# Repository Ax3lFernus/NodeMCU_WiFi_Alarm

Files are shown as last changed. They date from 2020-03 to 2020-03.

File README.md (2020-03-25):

# NodeMCU WiFi Alarm Logo NodeMCU WiFi Alarm
A simple firmware that makes NodeMCU a Wireless alarm center.

  

## Table of Contents
- [Features](#features)
  - [RC522 Support](#rc522-support)
  - [Wireless Connectivity](#wireless-connectivity)
  - [APIs](#apis)
  - [Web Panel](#web-panel)
- [Installation](#installation)
  - [Wiring Diagram](#wiring-diagram)
  - [Flash firmware](#flash-firmware)
  - [Change the timers](#change-the-timers)
  - [Install Web Panel](#install-web-panel)
- [The Author](#the-author)
- [License](#license)

## Features
### RC522 Support
With the RFID-RC522 card it is possible to activate and deactivate the alarm via an RFID tag or card.
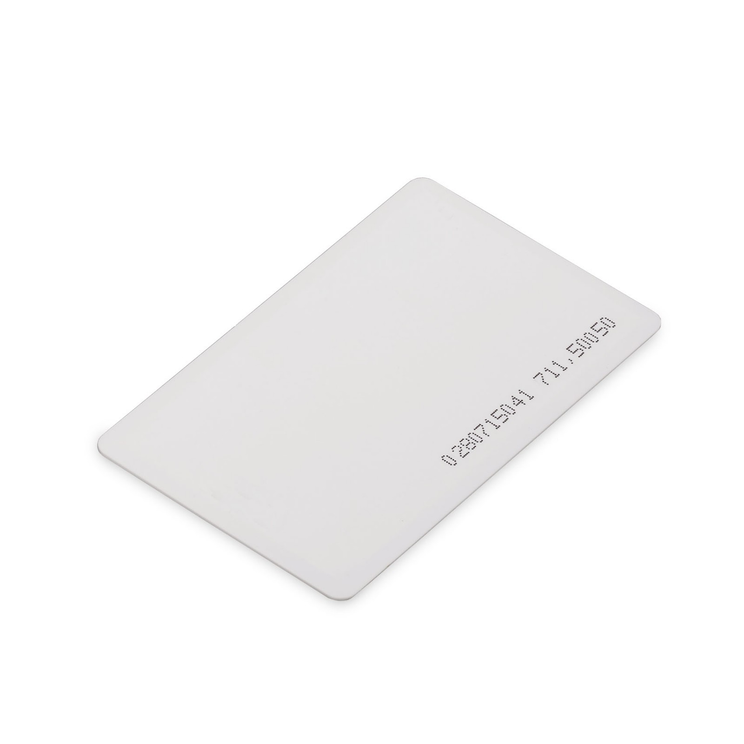
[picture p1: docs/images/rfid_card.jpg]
RFID Card
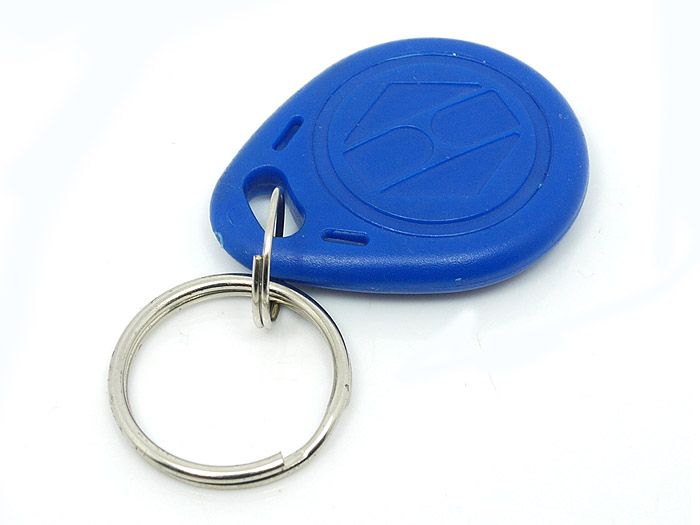
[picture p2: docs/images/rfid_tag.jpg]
RFID Tag
&nbsp;
### Wireless Connectivity
The NodeMCU card was born to have an integrated WiFi NIC. This functionality is used to check the card to read its status through the [APIs](#apis).
### APIs
The APIs provide commands to check and modify the alarm status. 
It is necessary to know the local IP of the card in order to interact with it through HTTP GET requests, the answers are in json format.
Here is the list of possible requests:
<ol>
<li>
To know the status of the card just send the request to http://CARD_IP/status. The answer is formatted as 

| Key | Type | Values | Description |
|---|---|---|---|
|door| String | `open` or `closed` | The value indicates whether the line of pin `D1` is open or closed. |
|h24 | String | `open` or `closed` | The value indicates whether the line of pin `D2` (tamper) is open or closed. |
|active| Bool| `true` or `false` | Indicates the alarm status: active (`true`) or inactive (`false`) |
|alarm | Bool| `true` or `false` | Indicates whether there is an alarm state. If `true`, the siren is in alarm. `false` otherwise. |
</li>
<li>
To activate the alarm just send the request to http://CARD_IP/1/on

| Key | Type | Values | Description |
|---|---|---|---|
|result| Bool | `true` or `false` | If `true`, the alarm is active. If `false`, the alarm is not active. |
|msg | String | - | A message written in natural language useful to describe the `result` key.  |
</li>
<li>
To deactivate the alarm just send the request to http://CARD_IP/1/off

| Key | Type | Values | Description |
|---|---|---|---|
|result| Bool | `true` or `false` | If `true`, the alarm is active. If `false`, the alarm is not active. |
|msg | String | - | A message written in natural language useful to describe the `result` key.  |
</li>
</ol>

### Web Panel

## Installation
### Wiring Diagram
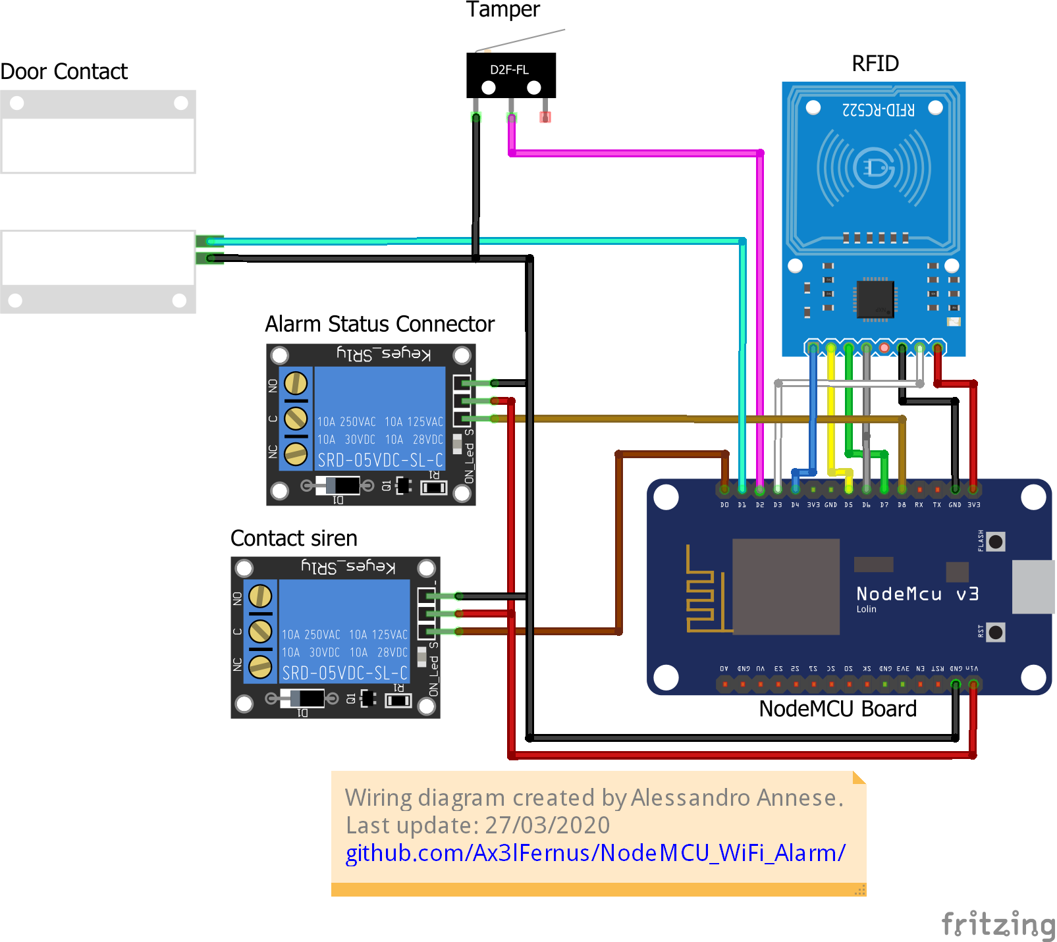
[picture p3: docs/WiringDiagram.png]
Wiring Diagram


The role of each pin used in the board is described below:
|Pin|Description|
| --- | --- |
|D0|It gives the signal to the siren to make it sound|
|D1|Detects the status of the door contact|
|D2|Detects the status of the tamper contact|
|D3|Reserved for the RST pin of the RFID board|
|D4|Reserved for the SDA pin of the RFID board|
|D5|Reserved for the SCK pin of the RFID board|
|D6|Reserved for the MISO pin of the RFID board|
|D7|Reserved for the MOSI pin of the RFID board|
|D8|Indicates the alarm status (enabled/disabled)|

### Flash firmware
You can flash the firmware on the NodeMCU via the [Arduino IDE](https://www.arduino.cc/en/Main/Software).
If you install the id for the first time you will need:
<ol>
<li>
Go to File -> Preferences -> add the link http://arduino.esp8266.com/stable/package_esp8266com_index.json in "Additional Boards Manager URLs" -> Click "OK"
</li>
<li>
Go to Tools -> Board -> click on "Boards Manager" -> search "esp8266" -> select leatest version -> click "Install" -> when finished click "Close"
</li>
<li>
Go to Tools and check this configurations:

| Name | Value |
|---|---|
| Board| NodeMCU 1.0 (ESP-12E Module)|
|Upload Speed| 115200|
|Port|Select the COM port where the board is connected| 
</li> 
<li>
Download the <a href="https://github.com/miguelbalboa/rfid/releases/latest/">source code</a> of the RFID library -> open Arduino IDE and go to Sketch -> Include Library -> Add .ZIP Library... -> select the previously downloaded .zip file -> click Open.
</li>
<li>
Go to File -> Open -> select 'firmware.ino' file from the repository directory on your pc -> when the code opens go to "Network SSID" and "Network PASSWORD" in the code and insert your network credentials between the quotes

`// Network and UID Credentials`<br>
`const char *ssid = "<YOUR WIFI NAME HERE>";          //Network SSID`<br>

`const char *password = "<YOUR WIFI PASSWORD HERE>"; //Network PASSWORD`<br>

`const char *UID = "<UID CARD HERE>";                //UID Card Code`<br>
</li>
<li>
In "UID Card Code" enter the code of your card for enable/disable the alarm.
</li>
<li>
Click on the arrow pointing to the right to flash the card.
</li>
<li>
That's all!
</li>
</ol>

**:information_source: Note:** if you don't know the uid of your card you will need to: flash the card -> open the serial monitor (select the value 115200 as baud rate) -> scan the RFID card -> copy the UID that comes out in the monitor -> go to step 5.

### Change the timers
The alarm has times that can be changed at will:
- Exit time (from when the alarm is activated until the door is detected open)
- Entry time (from when the door is opened to the sound of the siren)
- Alarm time
- Tamper detection time (from when the alarm is deactivated until the open tamper is detected)

Times are expressed in milliseconds. Ex: for 10 seconds we will have to enter the value 10000. 

So `milliseconds = seconds * 1000`.

You can change the value of timers by finding the respective variables in the code:

`// Define siren sound time in case of alarm (in milliseconds, example: 10000ms = 10s)`<br>
`const long alarmTimeout = 180000;`

This line expresses the alarm time. To change it to 10 seconds just change the variable:

`const long alarmTimeout = 10000;`

This applies to all timers.

**:warning: Danger zone:** It isn't recommended to change the `timeoutTime` variable as it is reserved for the Web server.

### Install Web Panel
The web panel doesn't require installation so you can open `./webServer/index.html` with a browser without using additional programs. The only step is to open the `index.html` with a text editor (es. Notepad++) and insert the ip of the card in the local network in the field `nodemcu_ip`:<br>
`let nodemcu_ip = "<NODEMCU IP HERE>" //Set your NodeMCU IP ex: 192.168.1.1`<br>
However, you can upload the `index.html` to a web server to be able to visit it from other devices on the same local network.

**:warning: Warning:** the panel must be started on a device connected in the same local network as the NodeMCU board.
## The Author
This software was developed by Alessandro Annese.<br>
You can follow me on:<br>
[Linkedin](https://www.linkedin.com/in/alessandro-annese-79683913b/)<br>
[GitHub](https://github.com/Ax3lFernus)

## License
[BSD 3-Clause License](https://github.com/Ax3lFernus/NodeMCU_WiFi_Alarm/blob/master/LICENSE)

Copyright &copy; 2020, Alessandro Annese<br>
All rights reserved.

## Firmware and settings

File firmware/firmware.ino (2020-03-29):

/*
 *  /$$   /$$                 /$$           /$$      /$$  /$$$$$$  /$$   /$$        /$$$$$$  /$$                                  
 * | $$$ | $$                | $$          | $$$    /$$$ /$$__  $$| $$  | $$       /$$__  $$| $$                                  
 * | $$$$| $$  /$$$$$$   /$$$$$$$  /$$$$$$ | $$$$  /$$$$| $$  \__/| $$  | $$      | $$  \ $$| $$  /$$$$$$   /$$$$$$  /$$$$$$/$$$$ 
 * | $$ $$ $$ /$$__  $$ /$$__  $$ /$$__  $$| $$ $$/$$ $$| $$      | $$  | $$      | $$$$$$$$| $$ |____  $$ /$$__  $$| $$_  $$_  $$
 * | $$  $$$$| $$  \ $$| $$  | $$| $$$$$$$$| $$  $$$| $$| $$      | $$  | $$      | $$__  $$| $$  /$$$$$$$| $$  \__/| $$ \ $$ \ $$
 * | $$\  $$$| $$  | $$| $$  | $$| $$_____/| $$\  $ | $$| $$    $$| $$  | $$      | $$  | $$| $$ /$$__  $$| $$      | $$ | $$ | $$
 * | $$ \  $$|  $$$$$$/|  $$$$$$$|  $$$$$$$| $$ \/  | $$|  $$$$$$/|  $$$$$$/      | $$  | $$| $$|  $$$$$$$| $$      | $$ | $$ | $$
 * |__/  \__/ \______/  \_______/ \_______/|__/     |__/ \______/  \______/       |__/  |__/|__/ \_______/|__/      |__/ |__/ |__/
 * 
 * NodeMcu Alarm Firmware
 * Developed by Alessandro Annese 
 * GitHub: Ax3lFernus
 * E-Mail: a.annese99@gmail.com
 * Version v2.2 29-03-2020
 */

// Load Wi-Fi library
#include <ESP8266WiFi.h>
#include <MFRC522.h>
#define SS_PIN D4
#define RST_PIN D3

MFRC522 mfrc522(SS_PIN, RST_PIN); // Create MFRC522 instance

// Network and UID Credentials
const char *ssid = "";     //Network SSID
const char *password = ""; //Network PASSWORD
const char *UID = "";      //UID Card Code
const char *API_KEY = "";  //API KEY

// Set WebServer Port to 80
WiFiServer server(80);

// Variable to store the HTTP request
String header;

// Current time
unsigned long currentTime = millis();
// Previous time
unsigned long previousTime = 0;
// Define timeout time in milliseconds (example: 2000ms = 2s)
const long timeoutTime = 2000;

// Alarm time counting
unsigned long alarmPreviousTime = 0;
// Define siren sound time in case of alarm (in milliseconds, example: 10000ms = 10s)
const long alarmTimeout = 180000;

// Door time counting
// Previous time
unsigned long doorExitPreviousTime = 0, doorEnterPreviousTime = 0;
// Defines the entry time since the door is opened (in milliseconds, example: 10000ms = 10s)
const long doorEnterTimeout = 10000;
// Defines the exit time since the alarm is set to active (in milliseconds)
const long doorExitTimeout = 10000;

// Tamper time counting
unsigned long tamperPreviousTime = 0;
// Time that allows the tamper line to be opened when the alarm is deactivated (in milliseconds, example: 10000ms = 10s)
const long tamperTimeout = 10000;

// Board Pin setup
const int doorPin = D1, sirenPin = D0, h24Pin = D2, activeAlarmPin = D8;

// Define flags
bool alarmActive = false, inAlarm = false, doorOpened = false, tamperOpened = false;

void setup()
{
  pinMode(doorPin, INPUT_PULLUP);
  pinMode(h24Pin, INPUT_PULLUP);
  pinMode(sirenPin, OUTPUT);
  pinMode(activeAlarmPin, OUTPUT);
  digitalWrite(sirenPin, HIGH);
  digitalWrite(activeAlarmPin, LOW);

  Serial.begin(115200);
  if (API_KEY == "" && ssid == "")
  {
    Serial.println("\nERROR: Missing variables.");
    while (true)
    {
      digitalWrite(activeAlarmPin, HIGH);
      delay(500);
      digitalWrite(activeAlarmPin, LOW);
      delay(500);
    };
  }
  WiFi.begin(ssid, password);
  while (WiFi.status() != WL_CONNECTED)
  {
    delay(500);
  }
  Serial.println("Connected.");
  Serial.print("IP address: ");
  Serial.print(WiFi.localIP());
  Serial.println(" Alarm ready.");
  server.begin();
  SPI.begin();        // Initiate  SPI bus
  mfrc522.PCD_Init(); // Initiate MFRC522
  tamperPreviousTime = millis();
}

void loop()
{
  WiFiClient client = server.available(); // Listen for incoming clients
  rfidCardScanner();
  alarmCheck();
  sirenCheck();
  if (client)
  {                          // If a new client connects,
    String currentLine = ""; // make a String to hold incoming data from the client
    currentTime = millis();
    previousTime = currentTime;
    while (client.connected() && currentTime - previousTime <= timeoutTime)
    { // loop while the client's connected
      currentTime = millis();
      if (client.available())
      {                         // if there's bytes to read from the client,
        char c = client.read(); // read a byte, then
        header += c;
        if (c == '\n')
        { // if the byte is a newline character
          // if the current line is blank, you got two newline characters in a row.
          // that's the end of the client HTTP request, so send a response:
          if (currentLine.length() == 0)
          {
            // HTTP headers always start with a response code (e.g. HTTP/1.1 200 OK)
            // and a content-type so the client knows what's coming, then a blank line:
            client.println("HTTP/1.1 200 OK");
            client.println("Access-Control-Allow-Origin: *");
            client.println("Access-Control-Max-Age: 2520");
            client.println("Access-Control-Allow-Methods: GET, PUT, DELETE, XMODIFY");
            client.println("Content-type:application/json");
            client.println("Connection: close");
            client.println();

            // Verify if are present commands in HTTP header
            if (header.indexOf("GET /1/on") >= 0)
            {
              setAlarm(true);
              client.print("{\"result\":");
              if (!alarmActive)
              {
                client.print("false,\"msg\":\"Error. Check the tamper line.\"}");
              }
              else
              {
                client.print("true,\"msg\":\"Alarm activated\"}");
              }
            }
            else if (header.indexOf("GET /1/off") >= 0)
            {
              setAlarm(false);
              client.print("{\"result\":true,\"msg\":\"Alarm deactivated\"}");
            }
            else if (header.indexOf("GET /status") >= 0)
            {
              client.print("{\"door\":");
              client.print(digitalRead(doorPin) == HIGH ? "\"open\"" : "\"closed\"");
              client.print(", \"h24\":");
              client.print(digitalRead(h24Pin) == HIGH ? "\"open\"" : "\"closed\"");
              client.print(", \"active\":");
              client.print(alarmActive ? "true" : "false");
              client.print(", \"alarm\":");
              client.print(inAlarm ? "true" : "false");
              client.print("}");
            }
            // The HTTP response ends with another blank line
            // Break out of the while loop
            break;
          }
          else
          { // if you got a newline, then clear currentLine
            currentLine = "";
          }
        }
        else if (c != '\r')
        {                   // if you got anything else but a carriage return character,
          currentLine += c; // add it to the end of the currentLine
        }
      }
    }
    // Clear the header variable
    header = "";
    // Close the connection
    client.stop();
  }
}

void rfidCardScanner()
{
  // Look for new cards
  if (!mfrc522.PICC_IsNewCardPresent())
  {
    return;
  }
  // Select one of the cards
  if (!mfrc522.PICC_ReadCardSerial())
  {
    return;
  }
  //Show UID on serial monitor
  Serial.println();
  Serial.print(" UID tag :");
  String content = "";
  byte letter;
  for (byte i = 0; i < mfrc522.uid.size; i++)
  {
    Serial.print(mfrc522.uid.uidByte[i] < 0x10 ? " 0" : " ");
    Serial.print(mfrc522.uid.uidByte[i], HEX);
    content.concat(String(mfrc522.uid.uidByte[i] < 0x10 ? " 0" : " "));
    content.concat(String(mfrc522.uid.uidByte[i], HEX));
  }
  content.toUpperCase();
  Serial.println();
  if (content.substring(1) == UID) //change UID of the card that you want to give access
  {
    Serial.println(" Access Granted ");
    if (inAlarm == true)
    {
      setAlarm(false);
      digitalWrite(sirenPin, HIGH);
    }
    else
      setAlarm(!alarmActive);
    delay(1000);
  }
  else
  {
    Serial.println(" Access Denied ");
    delay(3000);
  }
}

/**
  * Check the alarm status.
  * If alarm on, check the pins
  * Else do nothing
  */
void alarmCheck()
{
  // H24 Line protection
  if ((!(millis() - tamperPreviousTime <= tamperTimeout)))
    if (digitalRead(h24Pin) == HIGH && tamperOpened == false)
    {
      inAlarm = true;
      tamperOpened = true;
    }

  // Alarm active control
  if (alarmActive && inAlarm == false)
  {
    if (!(millis() - doorExitPreviousTime <= doorExitTimeout))
    {
      if (digitalRead(doorPin) == HIGH && doorOpened == false)
      {
        doorEnterPreviousTime = millis();
        doorOpened = true;
      }

      if ((!(millis() - doorEnterPreviousTime <= doorEnterTimeout)) && doorOpened == true)
      {
        inAlarm = true;
      }
    }
  }
}

/**
  * Set the alarm status.
  * Parameters: value -> true: Set the alarm on, false: Set the alarm off
  */
void setAlarm(bool value)
{
  doorOpened = false;
  tamperOpened = false;
  if (value)
  { //SET ALARM TO ON (with exit time)
    if (digitalRead(h24Pin) == HIGH)
    { // If h24Pin is open, send acustic feedback via siren
      digitalWrite(sirenPin, LOW);
      delay(500);
      digitalWrite(sirenPin, HIGH);
      delay(500);
      digitalWrite(sirenPin, LOW);
      delay(500);
      digitalWrite(sirenPin, HIGH);
      delay(500);
      digitalWrite(sirenPin, LOW);
      delay(500);
      digitalWrite(sirenPin, HIGH);
    }
    else
    {
      alarmActive = true;
      tamperPreviousTime = 0;
      digitalWrite(activeAlarmPin, HIGH);
      doorExitPreviousTime = millis();
    }
  }
  else
  { //SET ALARM TO OFF
    inAlarm = false;
    alarmActive = false;
    digitalWrite(activeAlarmPin, LOW);
    tamperPreviousTime = millis();
  }
}

/**
  * Check the siren status.
  * If inAlarm is true starts the siren
  * Else do nothing
  */
void sirenCheck()
{
  // In alarm status
  if (inAlarm)
  {
    //Alarm time counting
    if (millis() - alarmPreviousTime <= alarmTimeout)
    {
      digitalWrite(sirenPin, LOW);
    }
    else
    {
      //setAlarm(false);
      digitalWrite(sirenPin, HIGH);
    }
  }
  else
  {
    alarmPreviousTime = millis();
    digitalWrite(sirenPin, HIGH);
  }
}

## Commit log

2020-03-20 Renamed file for Arduino IDE
2020-03-20 Updated firmware to v2.0
    In this version it has been inserted reading an RFID tag to enable and disable the alarm.
2020-03-21 Bug fixing in firmware
    [firmware.ino]
2020-03-21 Firmware code refactoring
    - Added entry and exit times for the door pin
    - Divided the alarm management system, siren and pin check into separate functions
2020-03-21 Uploaded connections scheme
    [ConnectionsScheme.fzz]
2020-03-21 Renamed files
    [ConnectionsSchema.fzz]
2020-03-21 Diagram update
    [ConnectionsSchema.fzz, WiringDiagram.fzz]
2020-03-21 Pin roles added to README
2020-03-21 Updated wiring diagram
    [WiringDiagram.fzz]
2020-03-22 Added timer for the tamper line
    When the alarm is deactivated, the timer starts and you can freely operate on the tamper line without the alarm being triggered
2020-03-23 Added compatibility with relays
2020-03-25 Update firmware.ino
    Added printing of the IP address in the serial monitor
